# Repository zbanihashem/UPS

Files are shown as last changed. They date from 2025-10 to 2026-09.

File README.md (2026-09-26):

# Smart UPS V1

A Raspberry Pi Pico based smart UPS designed for reliable backup power, battery protection, fault monitoring, and system status indication.

The project includes custom PCBs, embedded firmware, sensor monitoring, automatic mains/battery switching, and protection logic.

## V1 Goals

The primary goal of V1 is to build and operate a stable UPS prototype under real load for an extended test period.

V1 is intentionally focused on reliability rather than adding new features. The system is planned to operate for approximately four months so that hardware and firmware issues can be identified before designing V2.

## System Architecture

The system is divided into several functional sections:

- Control Board — Raspberry Pi Pico, RTC, OLED, buzzer and interfaces
- Power Board — power-path control, load switching and power monitoring
- Battery Board — battery temperature and gas monitoring
- LED Board — six system status indicators
- Firmware — fault detection, system policy, power control and display logic

## Firmware Architecture

The firmware is divided into independent modules:

- `Hardware` — low-level GPIO and hardware access
- `Sensors` — sensor acquisition
- `FaultEngine` — fault detection and fault levels
- `SystemPolicy` — system decisions based on detected faults
- `PowerControl` — load, charger and system-power control
- `DisplayManager` — OLED and LED status indication

Main firmware entry point:

`Firmware/UPSPhase1.ino`

## Current V1 Status

The core UPS power-control system is operational.

Verified functions include:

- Automatic startup when mains power is available
- Automatic transition from mains to battery
- Automatic transition back to mains
- Pico self-power hold while operating from battery
- Load disconnect on critical battery condition
- Charger inhibit control
- Complete control-system shutdown on critical battery condition
- Automatic restart when mains power returns
- Mains presence detection
- Battery voltage and current monitoring
- Battery temperature monitoring
- MQ-2 gas monitoring
- OLED status display
- RTC operation
- Buzzer control
- Six front-panel status LEDs

## Status LEDs

The front panel provides six indicators:

- Green — Mains
- Red — Fault
- White — Load
- Blue — Charge Enabled
- Yellow — Battery Operation
- Red — Critical / Danger

The Charge LED represents charger permission from the controller. It does not indicate measured charging current.

## Known V1 Limitations

V1 contains several hardware compromises discovered during integration testing.

These include:

- Passive diode OR power-path architecture
- Relay-based high-side load switching
- Charger module parasitic battery consumption
- Hardware modifications made during integration testing

These issues are being documented for correction in V2.

The current charger isolation issue will be addressed in V1 before extended operation.

## Repository Structure

- `Firmware/` — Raspberry Pi Pico firmware
- `Hardware/` — KiCad schematics, PCB designs and hardware documentation
- `Simulations/` — circuit simulations
- `README.md` — project overview and current status

## Development Strategy

V1 will be operated under real load for approximately four months.

During this period:

- faults and unexpected behavior will be recorded
- hardware modifications will be documented
- firmware changes will be version controlled
- design improvements will be collected for V2

V2 will incorporate the lessons learned from extended V1 operation.

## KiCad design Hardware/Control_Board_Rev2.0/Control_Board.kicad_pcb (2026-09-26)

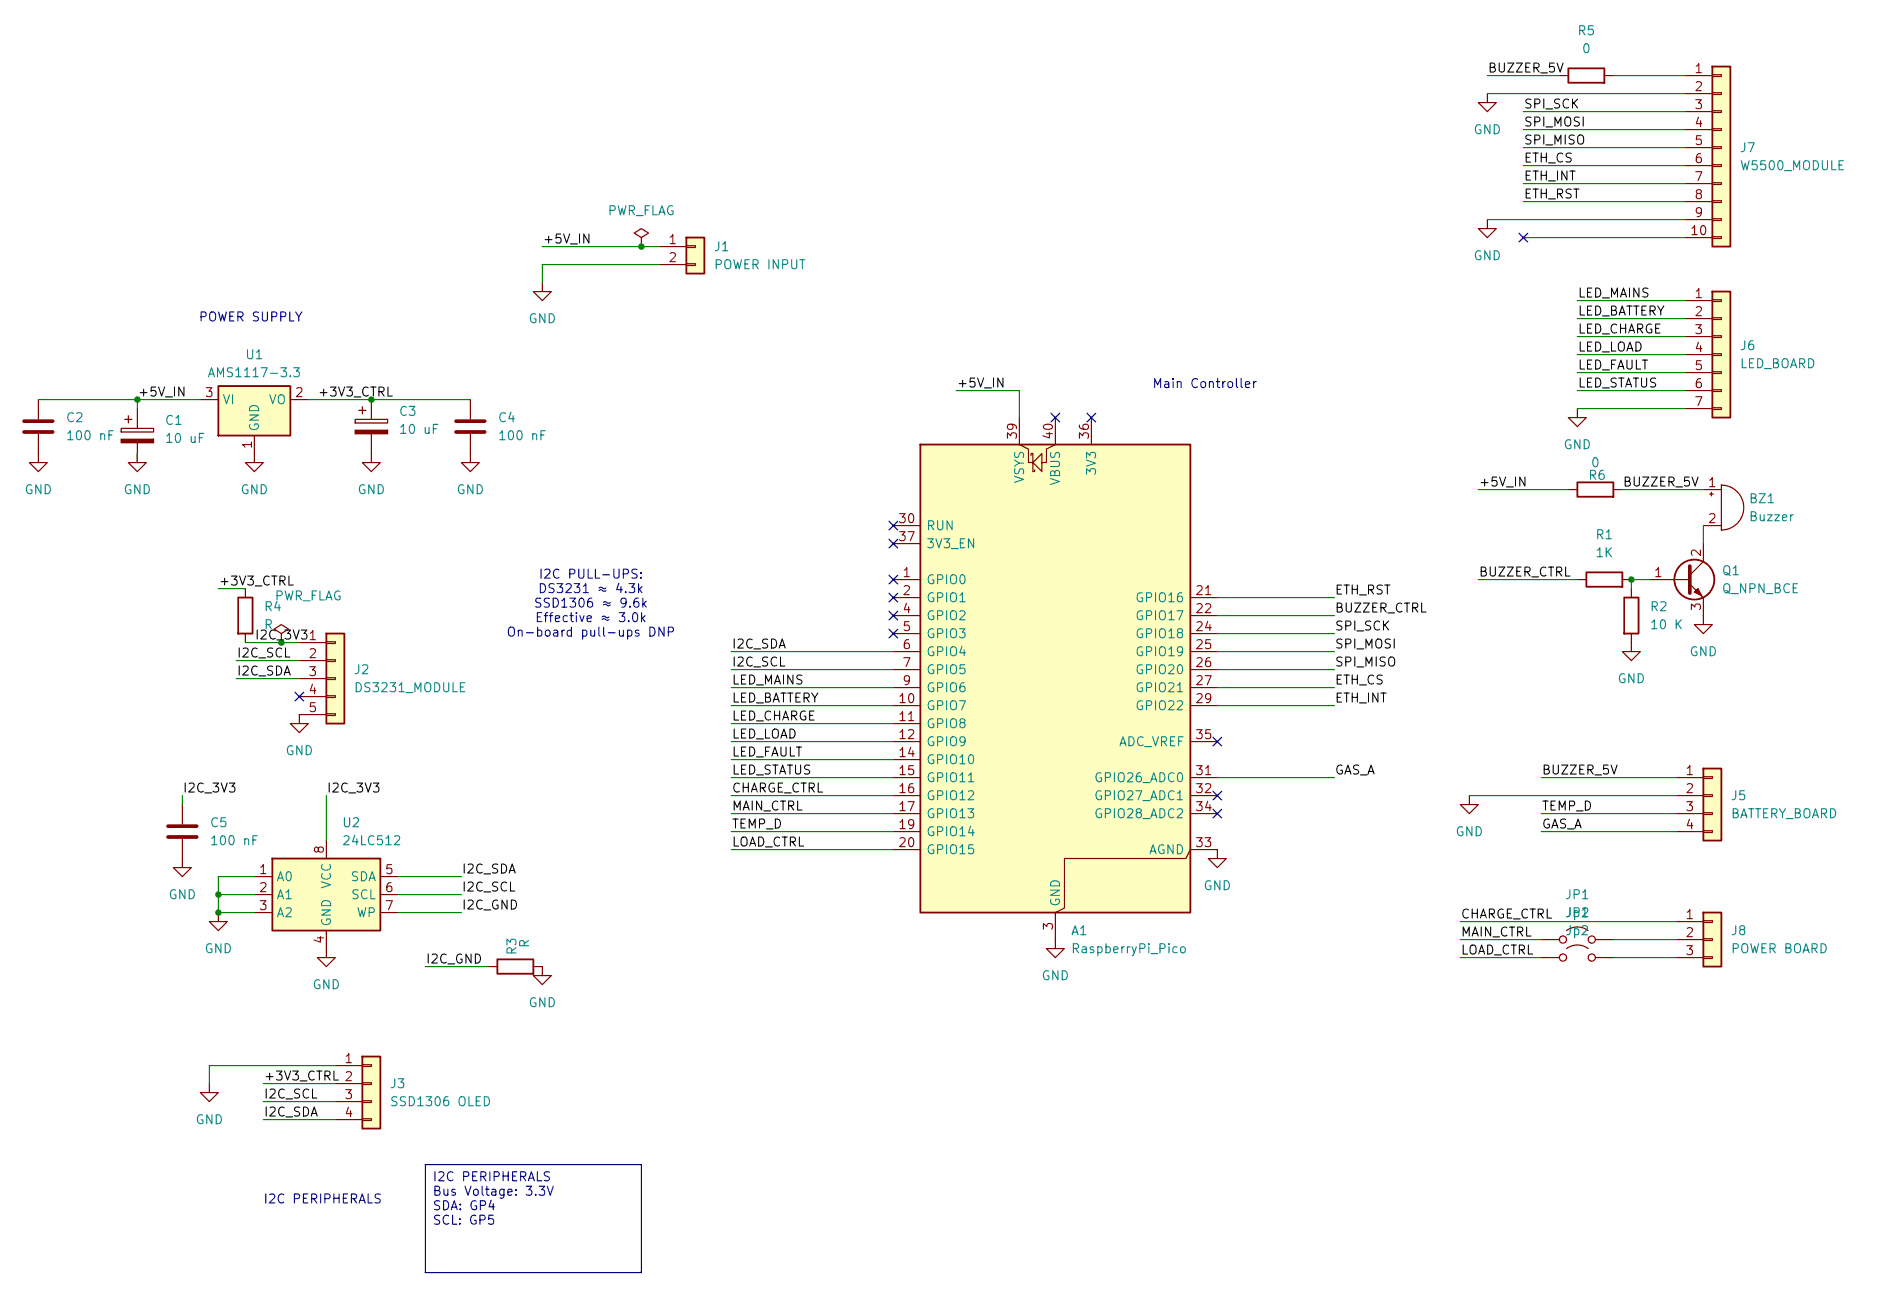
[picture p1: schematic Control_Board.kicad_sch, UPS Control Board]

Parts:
A1: RaspberryPi_Pico; RaspberryPi_Pico_Common_Unspecified
BZ1: Buzzer; Buzzer_12x9.5RM7.6
C1, C3: 10 uF; CP_Radial_D5.0mm_P2.50mm
C2, C4, C5: 100 nF; C_Disc_D4.7mm_W2.5mm_P5.00mm
J1: POWER INPUT; PinHeader_1x02_P2.54mm_Vertical
J2: DS3231_MODULE; PinHeader_1x05_P2.54mm_Vertical
J3: SSD1306 OLED; PinHeader_1x04_P2.54mm_Vertical
J5: BATTERY_BOARD; PinHeader_1x04_P2.54mm_Vertical
J6: LED_BOARD; PinHeader_1x07_P2.54mm_Vertical
J7: W5500_MODULE; PinHeader_1x10_P2.54mm_Vertical
J8: POWER BOARD; PinHeader_1x03_P2.54mm_Vertical
JP1: Jp1; Jumper_Harwin_S1621_P10.9mm
JP2: Jp2; Jumper_Harwin_S1621_P10.9mm
Q1: Q_NPN_BCE; TO-92-Large
R1: 1K; R_Axial_DIN0207_L6.3mm_D2.5mm_P10.16mm_Horizontal
R2: 10 K; R_Axial_DIN0207_L6.3mm_D2.5mm_P10.16mm_Horizontal
R3, R4: R; R_Axial_DIN0207_L6.3mm_D2.5mm_P10.16mm_Horizontal
R5, R6: 0; R_Axial_DIN0207_L6.3mm_D2.5mm_P10.16mm_Horizontal
U1: AMS1117-3.3; SOT-223-3_TabPin2
U2: 24LC512; SOIC-8_3.9x4.9mm_P1.27mm

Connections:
/+3V3_CTRL: C3.1, C4.1, J3.2, R4.1, U1.2 (VO)
/+5V_IN: A1.39 (VSYS), C1.1, C2.1, J1.1, R6.1, U1.3 (VI)
/BUZZER_5V: BZ1.1 (+), J5.1, R5.1, R6.2
/BUZZER_CTRL: A1.22 (GPIO17), R1.1
/CHARGE_CTRL: A1.16 (GPIO12), J8.1
/ETH_CS: A1.27 (GPIO21), J7.6
/ETH_INT: A1.29 (GPIO22), J7.7
/ETH_RST: A1.21 (GPIO16), J7.8
/GAS_A: A1.31 (GPIO26_ADC0), J5.4
/I2C_3V3: C5.1, J2.1, R4.2, U2.8 (VCC)
/I2C_GND: R3.1, U2.7 (WP)
/I2C_SCL: A1.7 (GPIO5), J2.2, J3.3, U2.6 (SCL)
/I2C_SDA: A1.6 (GPIO4), J2.3, J3.4, U2.5 (SDA)
/LED_BATTERY: A1.10 (GPIO7), J6.2
/LED_CHARGE: A1.11 (GPIO8), J6.3
/LED_FAULT: A1.14 (GPIO10), J6.5
/LED_LOAD: A1.12 (GPIO9), J6.4
/LED_MAINS: A1.9 (GPIO6), J6.1
/LED_STATUS: A1.15 (GPIO11), J6.6
/LOAD_CTRL: A1.20 (GPIO15), JP2.1 (A)
/MAIN_CTRL: A1.17 (GPIO13), JP1.1 (A)
/SPI_MISO: A1.26 (GPIO20), J7.5
/SPI_MOSI: A1.25 (GPIO19), J7.4
/SPI_SCK: A1.24 (GPIO18), J7.3
/TEMP_D: A1.19 (GPIO14), J5.3
GND: A1.3 (GND), A1.8 (GND), A1.13 (GND), A1.18 (GND), A1.23 (GND), A1.28 (GND), A1.33 (AGND), A1.38 (GND), C1.2, C2.2, C3.2, C4.2, C5.2, J1.2, J2.5, J3.1, J5.2, J6.7, J7.2, J7.9, Q1.3 (E), R2.2, R3.2, U1.1 (GND), U2.1 (A0), U2.2 (A1), U2.3 (A2), U2.4 (GND)
unnamed: BZ1.2 (-), Q1.2 (C)
unnamed: J7.1, R5.2
unnamed: J8.2, JP1.2 (B)
unnamed: J8.3, JP2.2 (B)
unnamed: Q1.1 (B), R1.2, R2.1

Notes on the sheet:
I2C PERIPHERALS
Main Controller
POWER SUPPLY
I2C PULL-UPS: DS3231 ≈ 4.3k SSD1306 ≈ 9.6k Effective ≈ 3.0k On-board pull-ups DNP
I2C PERIPHERALS Bus Voltage: 3.3V SDA: GP4 SCL: GP5

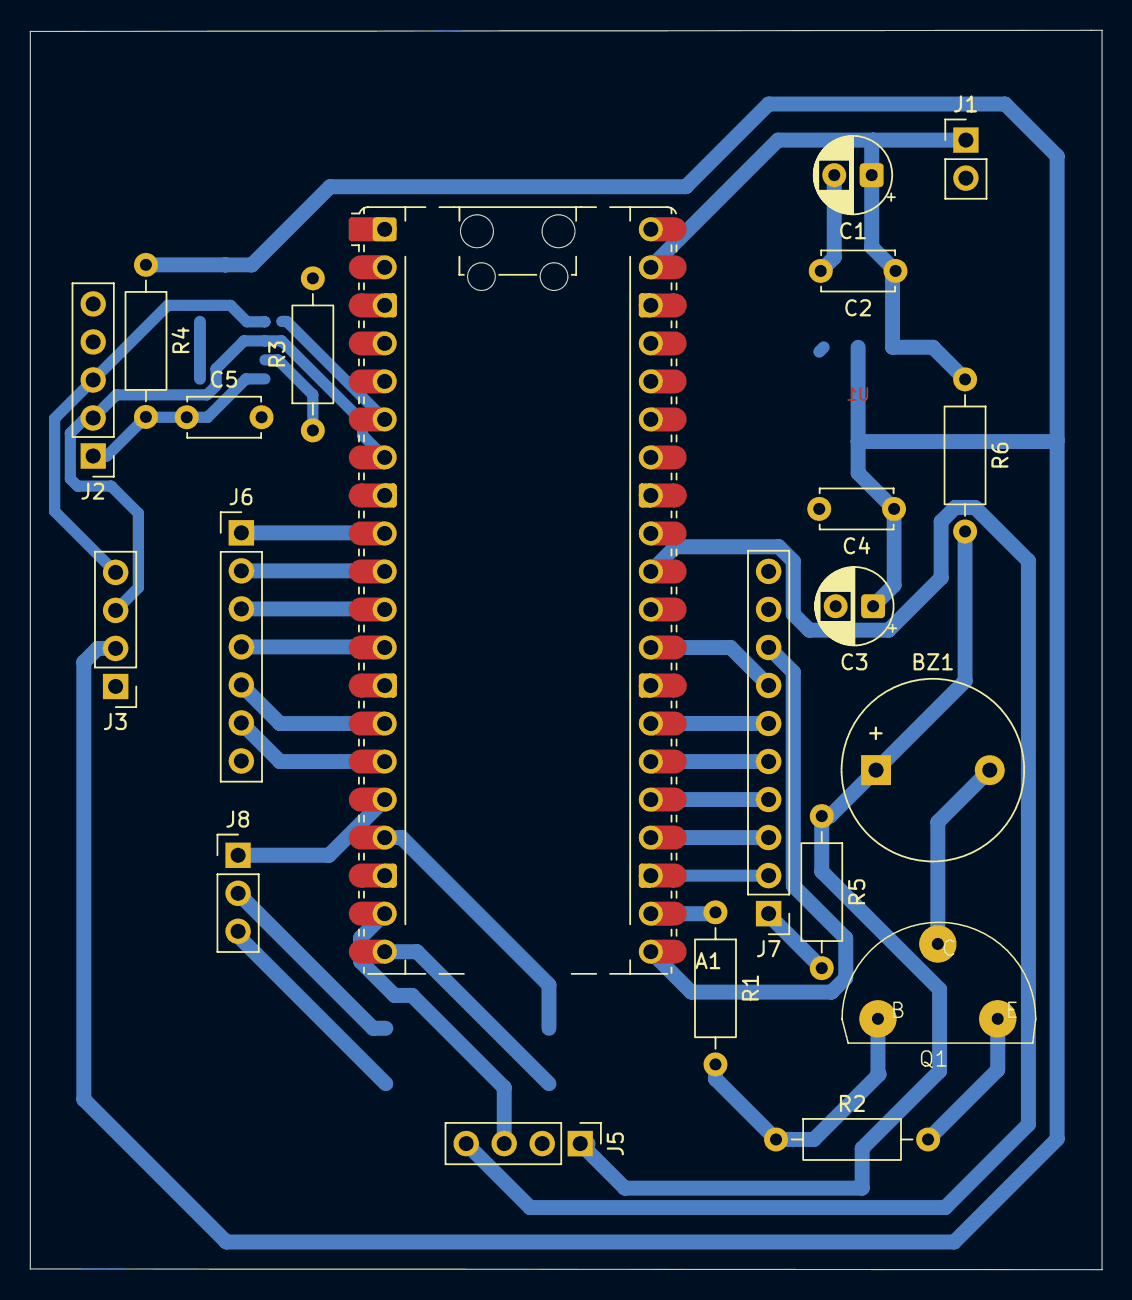
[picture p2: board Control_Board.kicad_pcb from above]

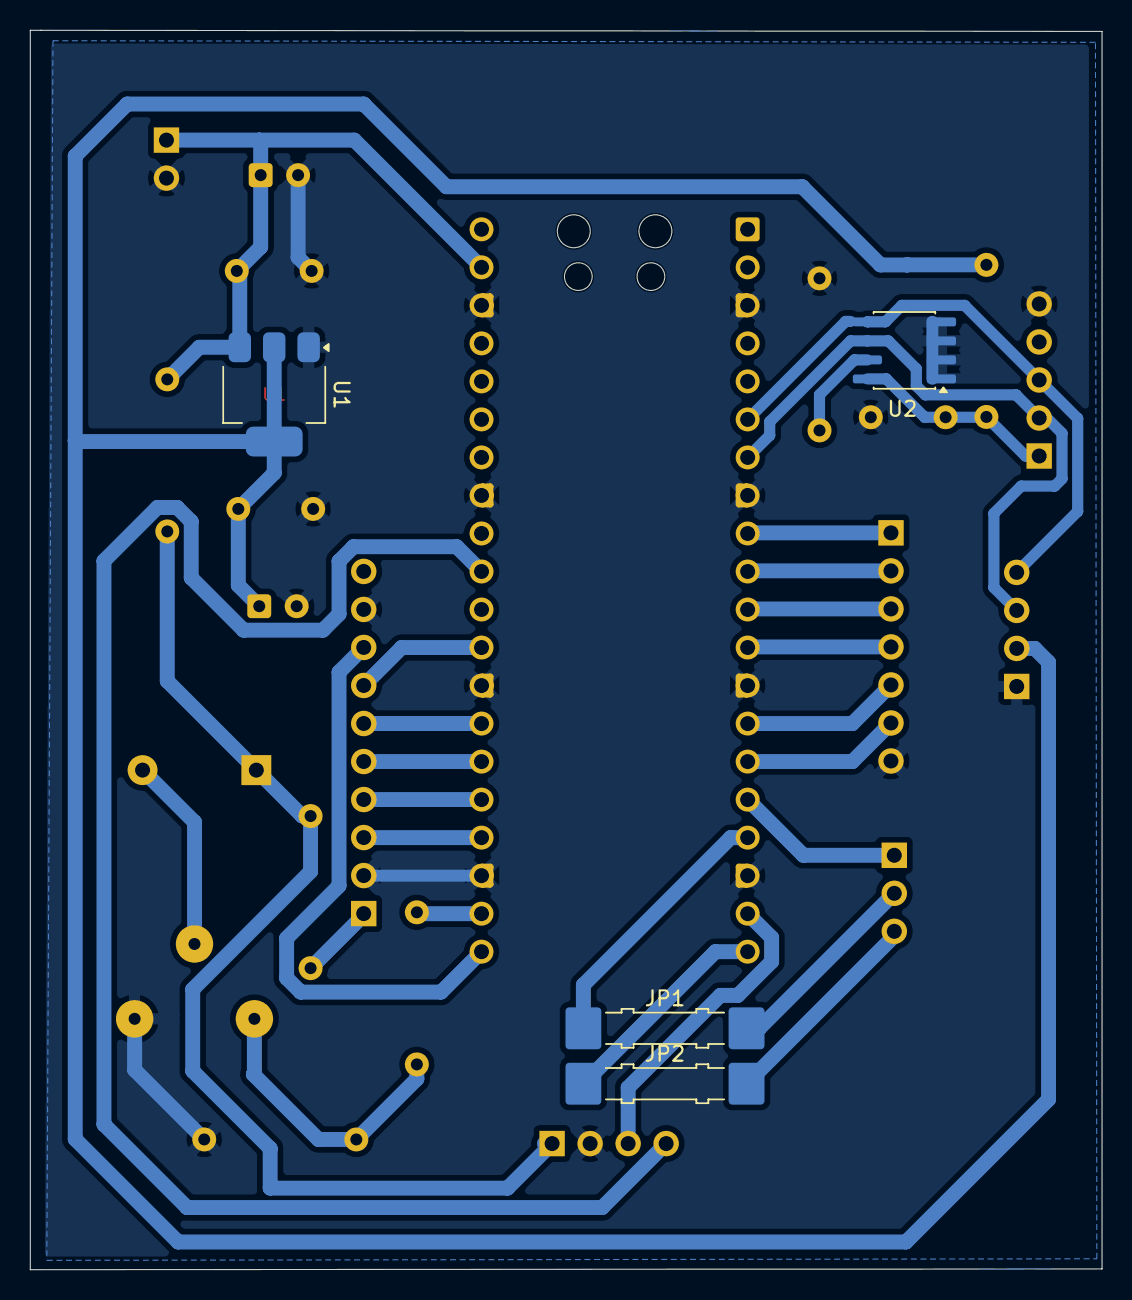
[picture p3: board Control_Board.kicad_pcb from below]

Board: 2 copper layers, 71.6 x 82.8 mm, 25 parts (4 on the bottom side), 31 nets.

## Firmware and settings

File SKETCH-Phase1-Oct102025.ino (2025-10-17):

#include <Arduino.h>
#include <U8g2lib.h>
#include <Wire.h>
#include <INA226_WE.h>
#include <OneWire.h>
#include <DallasTemperature.h>

// ======================= I/O Configuration =============================
#define I2C_ADDRESS 0x40
#define ONE_WIRE_BUS 14

// ======================= Safety Thresholds =============================

const float MIN_BATTERY_VOLTAGE = 11.5;
const float MAX_BATTERY_TEMP = 45.0;
const float SHUNT_RESISTOR = 0.06;

// ======================= Sensors =======================================
OneWire oneWire(ONE_WIRE_BUS);
DallasTemperature sensors(&oneWire);

// ======================= Display ( SPI SSD1325 ) =======================
INA226_WE ina226 = INA226_WE(I2C_ADDRESS);
U8G2_SSD1325_NHD_128X64_F_4W_HW_SPI u8g2(
  U8G2_R0,
  17, // cs
  16, // dc
  20  // reset
);

// ======================= Variables =====================================
float busVoltage = 0.0;
float shuntVoltage = 0.0 ;
float current_mA = 0.0;
float power_mW = 0.0;
float temperatureC = 0.0;
bool tempWarning = false;
bool voltageWarning = false;

// ======================= Warning Messages ==============================

const String voltageMessage = "LOW VOLTAGE!";
const String tempMessage = "HIGH TEMPERATURE!";
const String gasMessage = "GAS WARNING!";

void setup(void) {
  
  Wire.begin();
  delay(2000);
  sensors.begin();

  u8g2.begin();
  u8g2.clearBuffer();

  // Title text
  u8g2.setFont(u8g2_font_6x10_tr);
  u8g2.drawStr(20, 12, "Battery Status");

  if (!ina226.init()) {
    u8g2.drawStr(1, 15, "INA226 not found!");
    while (1);
  }

  ina226.setAverage(INA226_AVERAGE_16);
  ina226.setConversionTime(INA226_CONV_TIME_1100);
  ina226.setMeasureMode(INA226_CONTINUOUS);
  ina226.setResistorRange(0.1, 3.2);

  u8g2.drawStr(1, 20, "INA226 initialized successfully!");
  u8g2.sendBuffer();  
}


void loop(void) {

  busVoltage   = ina226.getBusVoltage_V();
  shuntVoltage = ina226.getShuntVoltage_mV();
  current_mA   = ina226.getCurrent_mA();
  power_mW     = busVoltage * (current_mA / 1000.0) * 1000.0;
  char buf[32];

// DS18B20 reading
  sensors.requestTemperatures();
  temperatureC = sensors.getTempCByIndex(0);

// Sfety Check
tempWarning = false;
voltageWarning = false;

if(busVoltage < MIN_BATTERY_VOLTAGE){
  voltageWarning = true;
}

else if (temperatureC > MAX_BATTERY_TEMP){
  tempWarning = true;
}
  u8g2.clearBuffer();
  u8g2.setCursor(0, 10);  u8g2.print("Bus: ");  u8g2.print(busVoltage, 2);  u8g2.print(" V");
  u8g2.setCursor(0, 22);  u8g2.print("Shunt: ");  u8g2.print(shuntVoltage, 2);  u8g2.print(" mV");
  u8g2.setCursor(0, 34);  u8g2.print("Current: ");  u8g2.print(current_mA, 2);  u8g2.print(" mA");
  u8g2.setCursor(0, 46);  u8g2.print("Temp: ");  u8g2.print(temperatureC, 2);  u8g2.print(" C");

  /*
  snprintf(buf, sizeof(buf), "Bus: %.1f V", busVoltage); u8g2.drawStr(0, 10, buf);  
  snprintf(buf, sizeof(buf), "Shunt: %.1f mV", shuntVoltage); u8g2.drawStr(0, 22, buf);  
  snprintf(buf, sizeof(buf), "Current: %.1f mA", current_mA); u8g2.drawStr(0, 34, buf);  
  //snprintf(buf, sizeof(buf), "Power: %.1f mW", power_mW); u8g2.drawStr(0, 46, buf);  
  snprintf(buf, sizeof(buf), "Temperature: %.1f C", tempC); u8g2.drawStr(0, 46, buf);
  */

  if(tempWarning) {
    u8g2.setCursor(0, 60);
    u8g2.print("WARN: ");
    u8g2.print(tempMessage);
  } 
  if(voltageWarning) {
    u8g2.setCursor(0, 60);
    u8g2.print("WARN: ");
    u8g2.print(voltageMessage);
  }
  
  u8g2.sendBuffer();
  delay(1000);  
}

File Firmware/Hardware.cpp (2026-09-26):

#include <sys/_types.h>
#include "Hardware.h"
#include <Wire.h>
#include <INA226_WE.h>
#include <OneWire.h>
#include <DallasTemperature.h>


// ======================= Sensors =======================================
OneWire oneWire(ONE_WIRE_BUS);
DallasTemperature sensors(&oneWire);
INA226_WE ina226 = INA226_WE(I2C_ADDRESS);

const float SHUNT_RESISTOR = 0.06;
unsigned long LastTempRequestTime = 0;


float HW::ReadGas()
{
  return analogRead(MQ2_ADC_PIN);
}

float HW::ReadTemperature()
{ 
  if(millis() - LastTempRequestTime < 750)
    return sensors.getTempCByIndex(0);

  sensors.requestTemperatures();
  LastTempRequestTime = millis();
  return sensors.getTempCByIndex(0);
}

void HW::init()
{
    Wire.setSDA(I2C_SDA_PIN);
    Wire.setSCL(I2C_SCL_PIN);
    Wire.begin();

    delay(2000);

    ina226.init();

    ina226.setAverage(INA226_AVERAGE_64);
    ina226.setConversionTime(INA226_CONV_TIME_1100);
    ina226.setMeasureMode(INA226_CONTINUOUS);
    ina226.setResistorRange(0.006, 4);

    sensors.begin();

    pinMode(CHARGE_PIN, OUTPUT);
    pinMode(MAIN_PIN, OUTPUT);
    pinMode(LOAD_PIN, OUTPUT);

    pinMode(BUZZER_PIN, OUTPUT);

    pinMode(LED_MAINS, OUTPUT);
    pinMode(LED_BATTERY, OUTPUT);
    pinMode(LED_CHARGE, OUTPUT);
    pinMode(LED_LOAD, OUTPUT);
    pinMode(LED_FAULT, OUTPUT);
    pinMode(LED_DANGER, OUTPUT);
    pinMode(MAINS_SENSE, INPUT);

    digitalWrite(CHARGE_PIN, LOW);
    digitalWrite(MAIN_PIN, HIGH);
    digitalWrite(LOAD_PIN, LOW);

    digitalWrite(BUZZER_PIN, LOW);

    digitalWrite(LED_MAINS, LOW);
    digitalWrite(LED_BATTERY, LOW);
    digitalWrite(LED_CHARGE, LOW);
    digitalWrite(LED_LOAD, LOW);
    digitalWrite(LED_FAULT, LOW);
    digitalWrite(LED_DANGER, LOW);    
}

void HW::ReadINA(INAData& data)
{
    //INAData data;
    data.bus_v = ina226.getBusVoltage_V();
    data.current = ina226.getCurrent_A();
    data.sunt_mv = ina226.getShuntVoltage_mV()/1000;
    data.power = ina226.getBusPower();
}

void HW::ControlLoad(bool loadState)
{
  if(loadState)
    digitalWrite(LOAD_PIN, HIGH);
  else
    digitalWrite(LOAD_PIN, LOW);

   //digitalWrite(LOAD_PIN, loadState ? HIGH : LOW);

    Serial.print("GP15 command=");
    Serial.print(loadState);
    Serial.print(" read=");
    Serial.println(digitalRead(LOAD_PIN));
}

void HW::ControlCharge(bool chargeState)
{
  if(chargeState)
    digitalWrite(CHARGE_PIN, HIGH);
  else
    digitalWrite(CHARGE_PIN, LOW);
}

void HW::SetBuzzer(bool on)
{
    //digitalWrite(BUZZER_PIN, on ? HIGH : LOW);
}

void HW::SetMainsLED(bool state)
{
    digitalWrite(LED_MAINS, state ? HIGH : LOW);
}

void HW::SetBatteryLED(bool state)
{
    digitalWrite(LED_BATTERY, state ? HIGH : LOW);
}

void HW::SetChargeLED(bool state)
{
    digitalWrite(LED_CHARGE, state ? HIGH : LOW);
}

void HW::SetLoadLED(bool state)
{
    digitalWrite(LED_LOAD, state ? HIGH : LOW);
}

void HW::SetFaultLED(bool state)
{
    digitalWrite(LED_FAULT, state ? HIGH : LOW);
}

void HW::SetDangerLED(bool state)
{
    digitalWrite(LED_DANGER, state ? HIGH : LOW);
}

void HW::ControlMain(bool state)
{
    digitalWrite(MAIN_PIN, state ? HIGH : LOW);  
}

bool HW::IsMainsPresent()
{
    return digitalRead(MAINS_SENSE);
}

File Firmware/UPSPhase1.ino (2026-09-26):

#include "Sensors.h"
#include "FaultEngine.h"
#include "PowerControl.h"
#include "SystemPolicy.h"
#include "DisplayManager.h"

Sensors sensorData;
FaultEngine faultEngine;
PowerControl power;
SystemPolicy policy(power);
DisplayManager display;
const char* faultMessages[5];
uint8_t faultCount = 0;

void setup()
{
   display.Init();
   sensorData.Init();
   //power.Begin(); // example pin
}

void loop()
{
    
    sensorData.ReadAll(sensorData);

    faultCount = faultEngine.Update(faultEngine, sensorData, faultMessages);

    policy.Apply(faultEngine);
    
    display.Update(faultCount, sensorData, faultEngine, faultMessages);

    delay(500);
}

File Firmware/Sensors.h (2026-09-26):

#include <sys/_stdint.h>
#ifndef SENSORS_H
#define SENSORS_H

#include <cstdint>
#include "Hardware.h"

class Sensors {
public:
    // Public read-only getters
    float GetBusVoltage() const { return busVoltage; }   // returns volts
    float GetShuntVoltage() const { return shuntVoltage; }   // returns volts
    float GetCurrent() const { return current; }   // returns amps
    int16_t GetGasPPM() const { return gasPPM; }
    float GetPower() const { return power; }
    int16_t GetTemperature() const { return temperature; }
    
    void UpdateFromINA(Sensors &ina);
    void UpdateTemperature(Sensors &temp);
    void UpdateGasLevel(Sensors &gasLevel);
    void ReadAll(Sensors &data);
    void Init();

private:
    float busVoltage= 0;
    float shuntVoltage= 0;
    float current = 0;
    float power= 0;
    int16_t gasPPM = 0;
    int16_t temperature = 0;
    
    void SetBusVoltageRaw(float v) { busVoltage = v; }
    void SetShuntVoltageRaw(float v) { shuntVoltage = v; }
    void SetCurrentRaw(float c) { current = c; }
    void SetGasRaw(int16_t g) { gasPPM = g; }
    void SetTemperature(int16_t t) { temperature = t; }
    void SetPower(float p) { power = p / 1000; }
};

#endif

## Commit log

2026-09-26 Refactor firmware and integrate UPS V1 power control
2026-09-26 Add KiCad hardware designs and custom footprints
    [Control_Board.kicad_pcb, Control_Board.kicad_sch]
